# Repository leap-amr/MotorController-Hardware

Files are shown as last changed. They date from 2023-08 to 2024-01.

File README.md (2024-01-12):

# MotorController-Hardware
モータドライバのハードウェア設計のためのリポジトリ

# Image
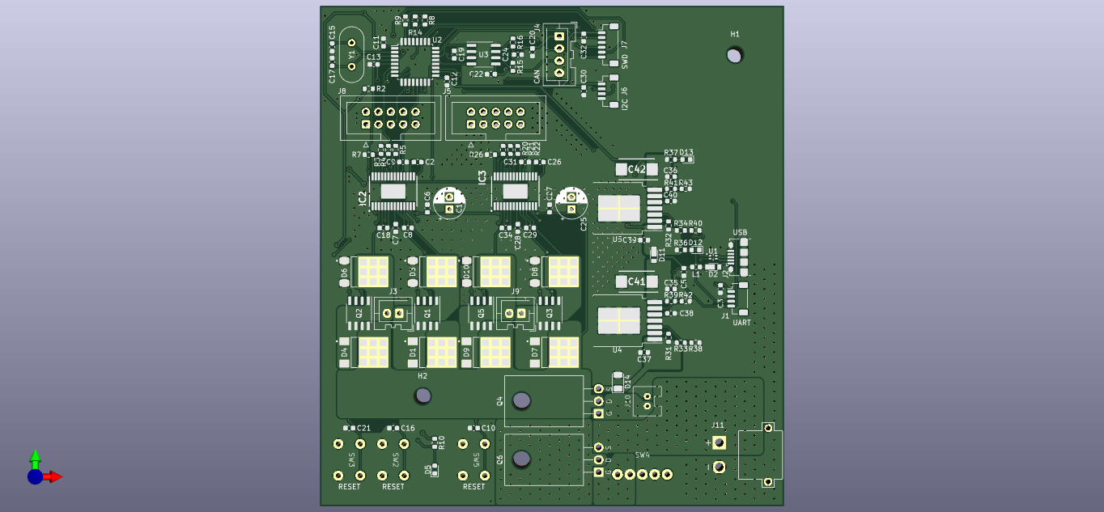
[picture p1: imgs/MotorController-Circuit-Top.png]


# Development Software Versions
Application: KiCad x64 on x64

Version: 7.0.6, release build

Libraries:
    wxWidgets 3.2.2
    FreeType 2.12.1
    HarfBuzz 6.0.0
    FontConfig 2.14.1
    libcurl/7.88.1-DEV Schannel zlib/1.2.13

Platform: Windows 10 (build 19045), 64-bit edition, 64 bit, Little endian, wxMSW

    Build Info:
    Date: Jul  6 2023 04:56:45
    wxWidgets: 3.2.2 (wchar_t,wx containers)
    Boost: 1.81.0
    OCC: 7.6.3
    Curl: 7.88.1-DEV
    ngspice: 40
    Compiler: Visual C++ 1936 without C++ ABI

Build settings:
    KICAD_SPICE=ON

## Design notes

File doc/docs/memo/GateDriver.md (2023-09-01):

# GateDriver
## A3921

### Functional Block Diagram
#### $C_{REG}$
A3921 内部にある 13 V にレギュレートされたピン $V_{REG}$ ピンと GND の間に接続する。

具体的な値の決め方は書いてない。

#### $C_p$
チャージポンプレギュレータに接続するコンデンサ。

200 nF 以上である必要があるが、通常 470 nF をつけておけば良いらしい。

#### $C_{BOOTA}, C_{BOOTB}$
ブートストラップに使用するコンデンサ。

ゲート電圧をより高くすハイサイドゲートを駆動するのに必要になる。

容量は

$$C_{BOOT} = \frac{Q_{GATE} \times 20}{V_{BOOT}}$$

で決めることができる。

|変数|説明|今回の回路の具体的な値
|:---:|:---
|$Q_{GATE}$|ゲート駆動に必要な電荷量|28 nC
|$V_{BOOT}$|ゲート駆動に必要な電圧|1.8 V

$Q_{BOOT} >> Q_{GATE}$ を満たす必要があり、ここでは $Q_{BOOT}$ を $Q_{GATE}$ の 20 倍の大きさを目安にしている。

∴311.111 nC 以上のコンデンサを選定する必要がある。

#### $R_{GHA}, R_{GHB}$
#### $R_{GLA}, R_{GLB}$
#### $R_{DEAD}$
#### V5
#### FF1, FF2
#### $V_{DSTH}$
#### SR
#### RESET

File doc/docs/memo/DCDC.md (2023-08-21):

# DC/DC Convertor
## TPSM13604HNDWR

### Typical Application
#### $R_{ENT}, R_{ENB}$
EN ピンの電圧が 1.18 V より大きいか小さいかで DC/DC コンバータの有効無効が決まる。

V_IN を分圧して、V_IN の電圧が規定値を下回った時に、EN ピンが 1.18 V を下回るように分圧抵抗を決める。

DC/DC コンバータが有効になる条件式

$$\frac{R_{ENB}}{R_{ENT} + R_{ENB}} \times V_{IN} \ge 1.18 [V]$$

#### $R_{FBT}, R_{FBB}$
FB ピンの電圧が 0.8 V より大きいか小さいかで DC/DC コンバータのパルス出力を有効にするか無効にするかが決まる。

V_OUT を分圧して、V_OUT の電圧が規定値を下回った時に、FB ピンが 0.8 V を下回るように分圧抵抗を決める。

出力電圧の式

$$\frac{R_{FBB}}{R_{FBT} + R_{FBB}} \times V_{OUT} = 0.8 [V]$$

出力電圧を 5 V にしたいときは $V_{OUT}$ を 5 V にする。

尚、これらの抵抗 $R_{FBT}, R_{FBB}$ の値は 1k ~ 50k $\Omega$ の範囲で選択する必要がある。

#### $C_{SS}$
推奨値 : 4700 pF

出力電圧が安定するまでの時間 $t_{SS}$ に関わる。

この時間は、早すぎると出力電圧がオーバーシュートし、遅すぎると目的の出力電圧を得るのに時間がかかってしまう。

$$t_{SS} = 0.8 [V] \times \frac{C_{SS}}{0.8 [\mu A]}$$

という式で求めることが可能だが、$t_{SS}= 0 .5 [ms]$ が推奨値とされているため、$C_{{SS}} = 4700 [pF]$ が推奨とされる。

#### $C_{OUT}$
推奨コンデンサ : セラミックコンデンサ or ポリマー電解コンデンサ

$$C_{OUT} \ge I_{STEP} \times V_{FB} \times L \times \frac{V_{IN}}{4 \times V_{OUT} \times (V_{IN} - V_{OUT}) \times V_{OUT-TRAN}}$$

ここで、

- $V_{FB}$ は FB ピンの閾値 0.8 V
- $L$ はインダクタのリアクタンス 10 $\mu H$
- $V_{OUT-TRAN}$ はなんだよこれ 例として $V_{OUT-TRAN} = 50 [mV]$ になってる
- $I_{STEP}$ はおそらく最大出力電流 DC/DC  の最大出力電流が 4 A であるためこれ以下にする
- $V_{IN}, V_{OUT}$ はそれぞれ入力電圧と出力電圧

これらによって $C_{OUT}$ の最小値が決定される。

この条件を満たしたうえで、低 ESR のコンデンサを設定する。

この ESR の最大値も計算式が用意されているがよくわからん。

#### $R_{ON}$
スイッチング周波数を決定する抵抗。

以下の式でスイッチング周波数 $f_{SW(CCM)}$ が決定される。

$$f_{SW(CCM)} \approxeq \frac{V_{OUT}}{(1.3\times10^{-10}\times R_{ON}}$$

#### $C_{IN}$
$$C_{IN} \geq \frac{I_{OUT} \times D \times ( 1 - D)}{f_{SW-CCM} \times \Delta{V_{IN}}}$$
$$D \approxeq \frac{V_{OUT}}{V_{IN}}$$

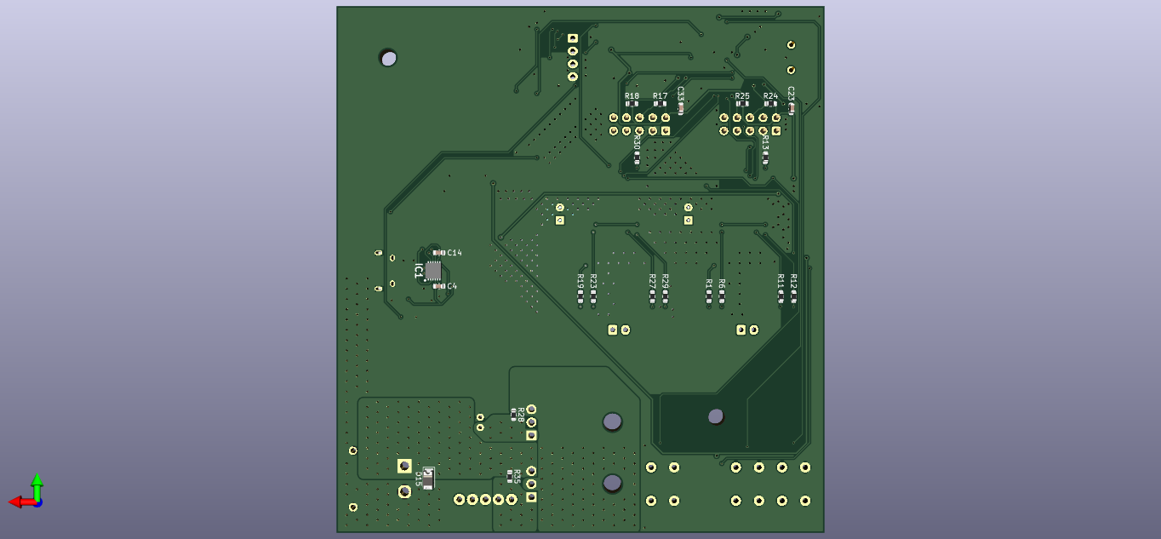
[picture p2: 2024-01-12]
imgs/MotorController-3D-Bottom.png

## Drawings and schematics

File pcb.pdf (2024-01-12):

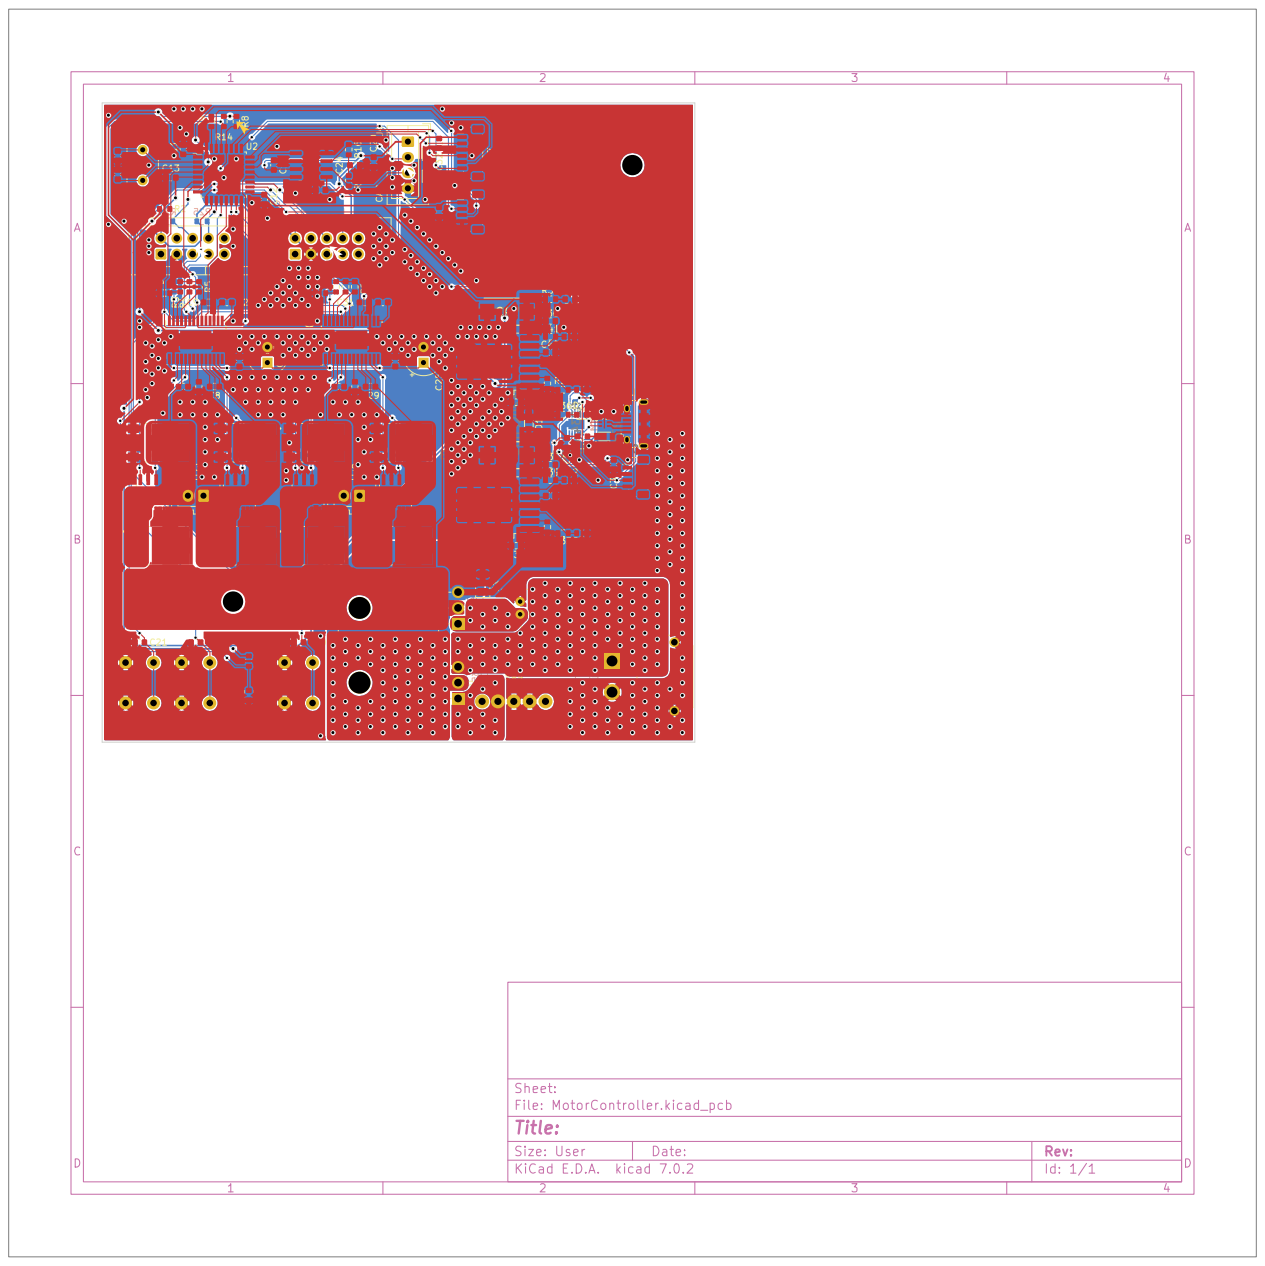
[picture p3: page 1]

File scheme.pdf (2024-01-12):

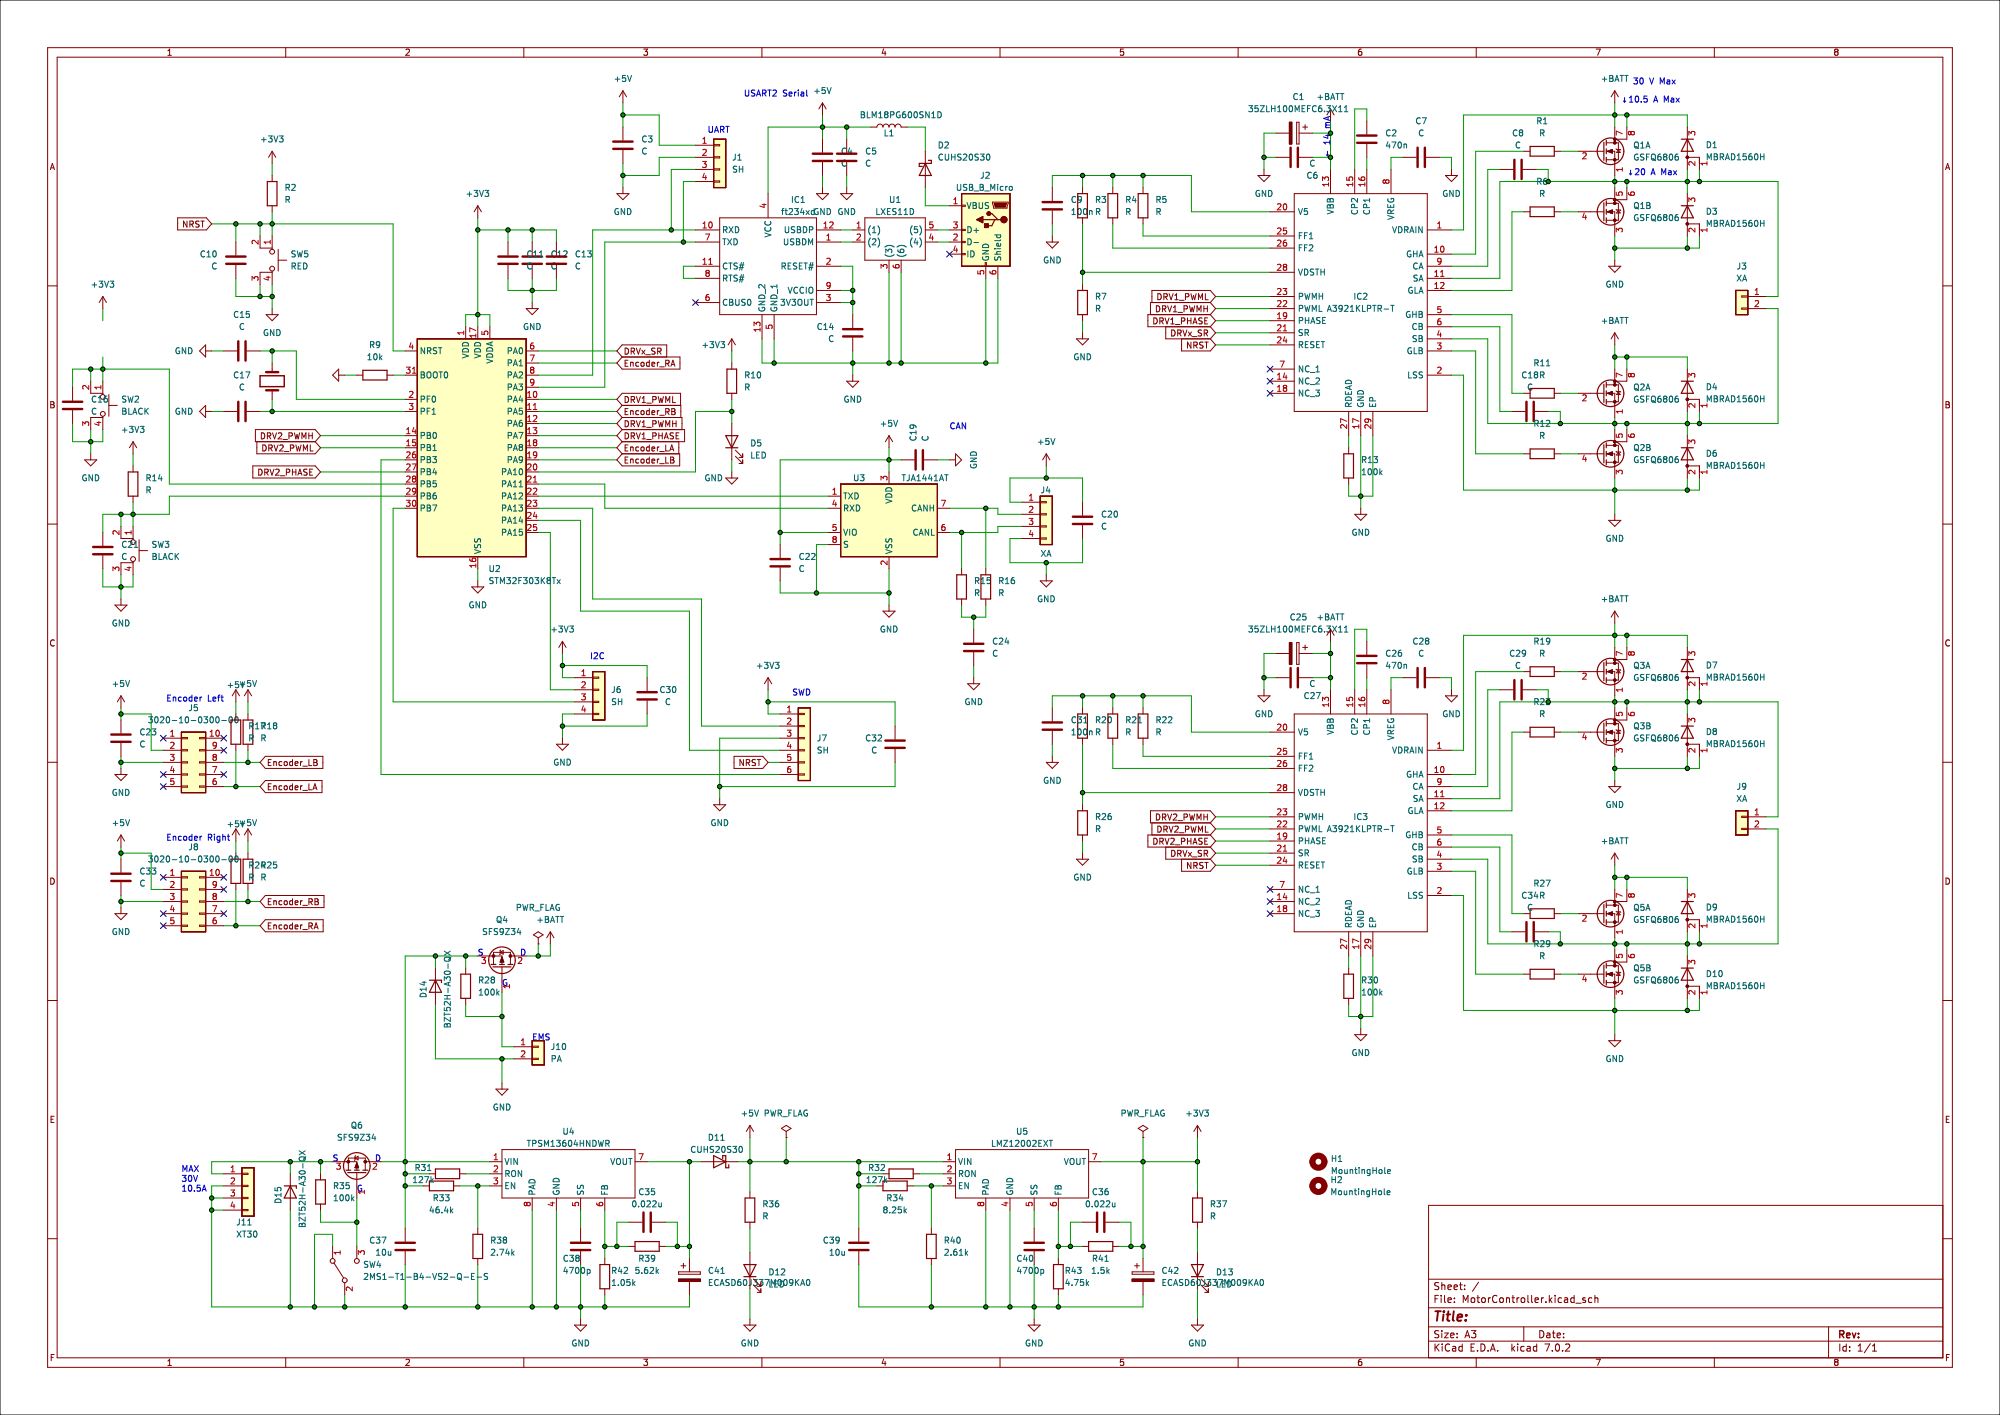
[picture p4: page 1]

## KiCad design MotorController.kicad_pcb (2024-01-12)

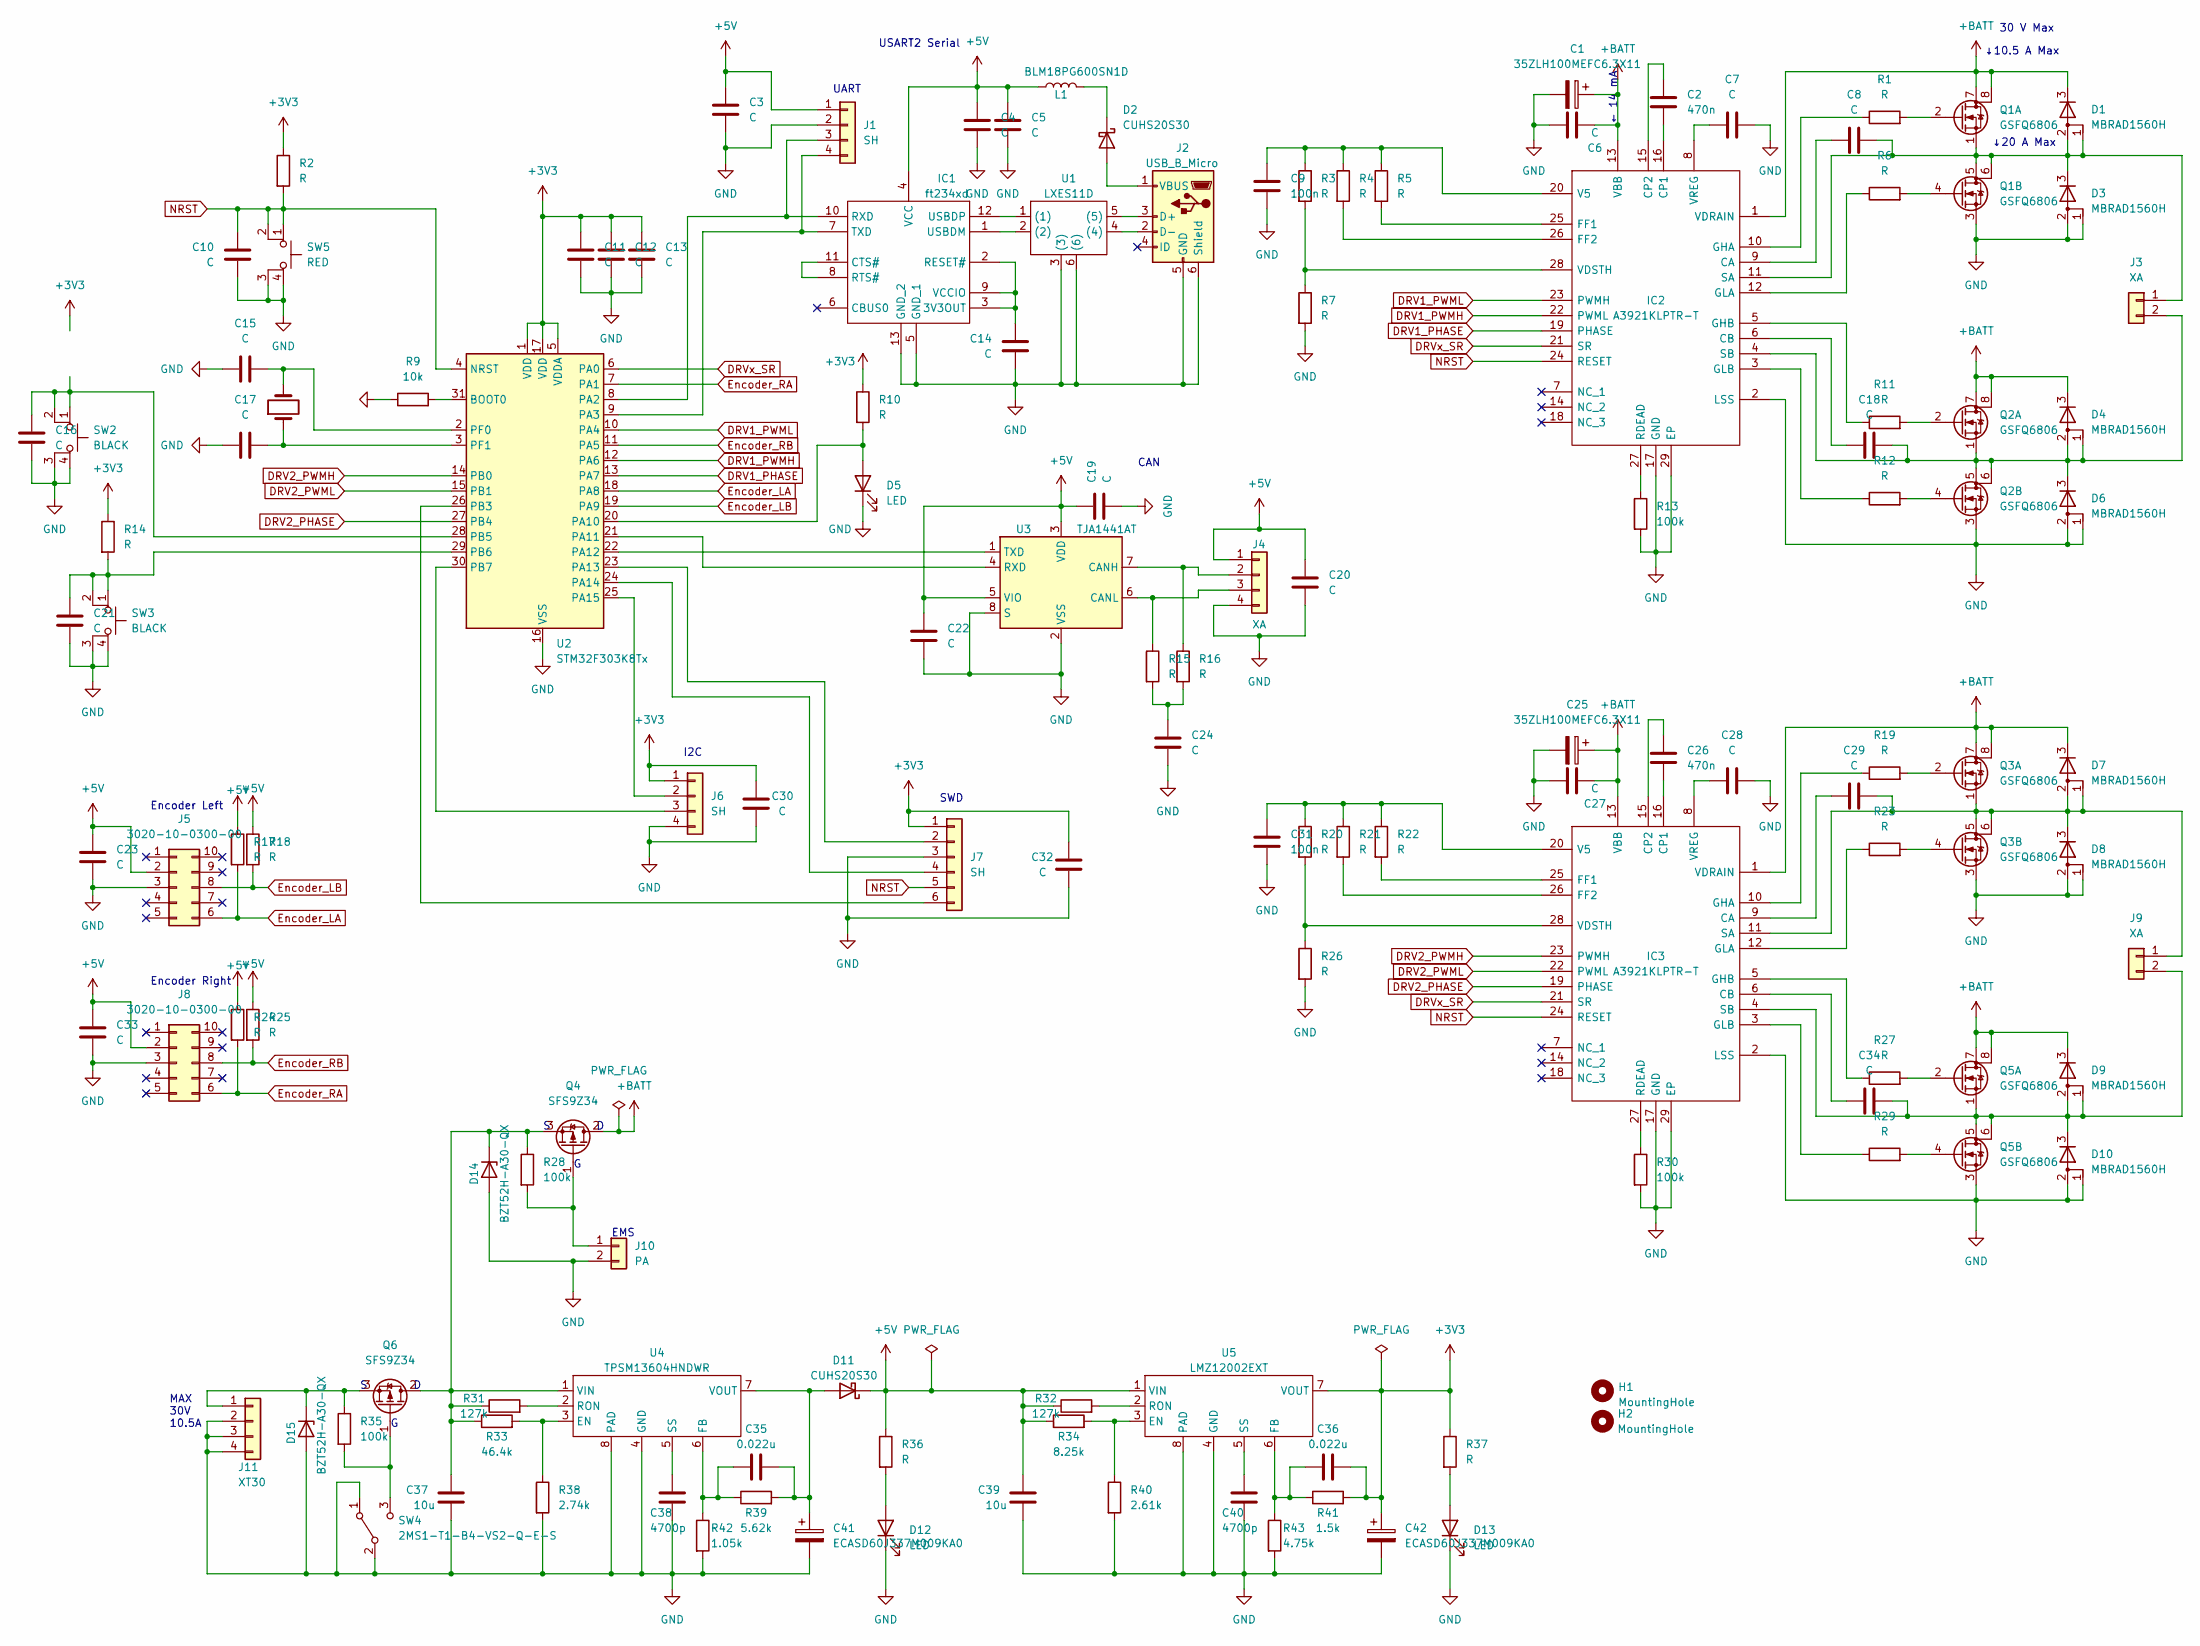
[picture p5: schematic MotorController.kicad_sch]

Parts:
C1, C25: 35ZLH100MEFC6.3X11; CP_Radial_D6.3mm_P2.50mm
C2, C26: 470n; C_0603_1608Metric
C3, C4, C5, C6, C7, C8, C10, C11, C12, C13, C14, C15, C16, C17, C18, C19, C20, C21, C22, C23, C24, C27, C28, C29, C30, C32, C33, C34: C; C_0603_1608Metric
C9, C31: 100n; C_0603_1608Metric
C35, C36: 0.022u; C_0603_1608Metric
C37, C39: 10u; C_0603_1608Metric
C38, C40: 4700p; C_0603_1608Metric
C41, C42: ECASD60J337M009KA0; CAPPM7343X310N
D1, D3, D4, D6, D7, D8, D9, D10: MBRAD1560H; DIO_MBRAD1560H
D2, D11: CUHS20S30; CUHS20S40H3F
D5, D12, D13: LED; LED_0603_1608Metric
D14, D15: BZT52H-A30-QX; D_1206_3216Metric
H1, H2: MountingHole; MountingHole_3.2mm_M3
IC1: ft234xd; SON45P300X300X80-13N-D; Manufacturer_Part_Number ft234xd
IC2, IC3: A3921KLPTR-T; A3944KLPTRT; Manufacturer_Part_Number A3921KLPTR-T; Mouser Part Number 250-A3921KLPTR-T
J1, J6: SH; JST_SH_BM04B-SRSS-TB_1x04-1MP_P1.00mm_Vertical
J2: USB_B_Micro; USB_Micro-B_Amphenol_10118194_Horizontal
J3, J9: XA; JST_XA_B02B-XASK-1-A_1x02_P2.50mm_Vertical
J4: XA; JST_XA_B04B-XASK-1-A_1x04_P2.50mm_Vertical
J5, J8: 3020-10-0300-00; IDC-Header_2x05_P2.54mm_Vertical
J7: SH; JST_SH_BM06B-SRSS-TB_1x06-1MP_P1.00mm_Vertical
J10: PA; PA_01x02
J11: XT30; XT30PWM
L1: BLM18PG600SN1D; L_0603_1608Metric
Q1, Q2, Q3, Q5: GSFQ6806; SO-8_3.9x4.9mm_P1.27mm
Q4, Q6: SFS9Z34; TO-220F-3_Horizontal_TabDown
R1, R2, R3, R4, R5, R6, R7, R10, R11, R12, R14, R15, R16, R17, R18, R19, R20, R21, R22, R23, R24, R25, R26, R27, R29, R36, R37: R; R_0603_1608Metric
R9: 10k; R_0603_1608Metric
R13, R28, R30, R35: 100k; R_0603_1608Metric
R31, R32: 127k; R_0603_1608Metric
R33: 46.4k; R_0603_1608Metric
R34: 8.25k; R_0603_1608Metric
R38: 2.74k; R_0603_1608Metric
R39: 5.62k; R_0603_1608Metric
R40: 2.61k; R_0603_1608Metric
R41: 1.5k; R_0603_1608Metric
R42: 1.05k; R_0603_1608Metric
R43: 4.75k; R_0603_1608Metric
SW2, SW3: BLACK; DTS-63-N-V-BLK(TS-0606-F-N
SW4: 2MS1-T1-B4-VS2-Q-E-S
SW5: RED; DTS-63-N-V-BLK(TS-0606-F-N
U1: LXES11D; LXES11DAA2135
U2: STM32F303K8Tx; LQFP-32_7x7mm_P0.8mm
U3: TJA1441AT; SOIC-8_3.9x4.9mm_P1.27mm
U4: TPSM13604HNDWR; Texas_NDW-7_TabPin8
U5: LMZ12002EXT; Texas_NDW-7_TabPin8
Y1: 32M; Crystal_HC49-4H_Vertical

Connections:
+3V3: C11.1, C12.1, C13.1, C30.1, C32.1, C36.2, C42.1, J6.1, J7.1, R2.1, R10.1, R14.1, R37.1, R41.2, U2.1 (VDD), U2.5 (VDDA), U2.17 (VDD), U5.7 (VOUT); also elsewhere on the board
+5V: C3.1, C4.1, C5.1, C19.1, C20.1, C22.1, C23.1, C33.1, C39.1, D11.1 (K), IC1.4 (VCC), J1.1, J4.1, J5.2, J8.2, L1.1, R17.1, R18.1, R24.1, R25.1, R32.1, R34.1, R36.1, U3.3 (VDD), U3.5 (VIO), U5.1 (VIN)
+BATT: C1.1, C6.2, C25.1, C27.2, D1.3 (K), D4.3 (K), D7.3 (K), D9.3 (K), IC2.1 (VDRAIN), IC2.13 (VBB), IC3.1 (VDRAIN), IC3.13 (VBB), Q1.7 (D), Q1.8 (D), Q2.7 (D), Q2.8 (D), Q3.7 (D), Q3.8 (D), Q4.2 (D), Q5.7 (D), Q5.8 (D)
DRV1_PHASE: IC2.19 (PHASE), U2.13 (PA7)
DRV1_PWMH: IC2.22 (PWML), U2.12 (PA6)
DRV1_PWML: IC2.23 (PWMH), U2.10 (PA4)
DRV2_PHASE: IC3.19 (PHASE), U2.27 (PB4)
DRV2_PWMH: IC3.23 (PWMH), U2.14 (PB0)
DRV2_PWML: IC3.22 (PWML), U2.15 (PB1)
DRVx_SR: IC2.21 (SR), IC3.21 (SR), U2.6 (PA0)
Encoder_LA: J5.6, R17.2, U2.18 (PA8)
Encoder_LB: J5.8, R18.2, U2.19 (PA9)
Encoder_RA: J8.6, R24.2, U2.7 (PA1)
Encoder_RB: J8.8, R25.2, U2.11 (PA5)
GND: C1.2, C3.2, C4.2, C5.2, C6.1, C7.2, C9.2, C10.2, C11.2, C12.2, C13.2, C14.2, C15.1, C16.2, C17.1, C19.2, C20.2, C21.2, C22.2, C23.2, C24.2, C25.2, C27.1, C28.2, C30.2, C31.2, C32.2, C33.2, C37.2, C38.2, C39.2, C40.2, C41.2, C42.2, D3.1 (A), D3.2 (A), D5.1 (K), D6.1 (A), D6.2 (A), D8.1 (A), D8.2 (A), D10.1 (A), D10.2 (A), D12.1 (K), D13.1 (K), D14.2 (A), D15.2 (A), IC1.5 (GND_1), IC1.13 (GND_2), IC2.2 (LSS), IC2.17 (GND), IC2.29 (EP), IC3.2 (LSS), IC3.17 (GND), IC3.29 (EP), J1.2, J2.5 (GND), J2.6 (Shield), J4.4, J5.3, J6.4, J7.3, J8.3, J10.2, J11.2, J11.3, J11.4, Q1.3 (S), Q2.3 (S), Q3.3 (S), Q5.3 (S), R7.2, R9.1, R13.2, R26.2, R30.2, R38.2, R40.2, R42.2, R43.2, SW2.3 (K), SW2.4 (A), SW3.3 (K), SW3.4 (A), SW4.1 (A), SW4.2 (B), SW5.3 (K), SW5.4 (A), U1.3 ((3)), U1.6 ((6)), U2.16 (VSS), U2.32 (VSS), U3.2 (VSS), U3.8 (S), U4.4 (GND), U4.8 (PAD), U5.4 (GND), U5.8 (PAD)
NRST: C10.1, IC2.24 (RESET), IC3.24 (RESET), J7.5, R2.2, SW5.1, SW5.2, U2.4 (NRST)
unnamed: C24.1, R15.2, R16.2
unnamed: D2.2 (A), J2.1 (VBUS)
unnamed: D2.1 (K), L1.2
unnamed: C8.1, D1.1 (A), D1.2 (A), D3.3 (K), IC2.11 (SA), J3.1, Q1.1 (S), Q1.5 (D), Q1.6 (D)
unnamed: D5.2 (A), R10.2, U2.20 (PA10)
unnamed: C18.1, D4.1 (A), D4.2 (A), D6.3 (K), IC2.4 (SB), J3.2, Q2.1 (S), Q2.5 (D), Q2.6 (D)
unnamed: C29.1, D7.1 (A), D7.2 (A), D8.3 (K), IC3.11 (SA), J9.1, Q3.1 (S), Q3.5 (D), Q3.6 (D)
unnamed: C34.1, D9.1 (A), D9.2 (A), D10.3 (K), IC3.4 (SB), J9.2, Q5.1 (S), Q5.5 (D), Q5.6 (D)
unnamed: C35.2, C41.1, D11.2 (A), R39.2, U4.7 (VOUT)
unnamed: D12.2 (A), R36.2
unnamed: D13.2 (A), R37.2
unnamed: C37.1, D14.1 (K), Q4.3 (S), Q6.2 (D), R28.1, R31.1, R33.1, U4.1 (VIN)
unnamed: D15.1 (K), J11.1, Q6.3 (S), R35.1
unnamed: C14.1, IC1.2 (RESET#), IC1.3 (3V3OUT), IC1.9 (VCCIO)
unnamed: IC1.8 (RTS#), IC1.11 (CTS#)
unnamed: IC1.10 (RXD), J1.3, U2.8 (PA2)
unnamed: IC1.7 (TXD), J1.4, U2.9 (PA3)
unnamed: IC1.1 (USBDM), U1.2 ((2))
unnamed: IC1.12 (USBDP), U1.1 ((1))
unnamed: C8.2, IC2.9 (CA)
unnamed: C18.2, IC2.6 (CB)
unnamed: C2.1, IC2.16 (CP1)
unnamed: C2.2, IC2.15 (CP2)
unnamed: IC2.25 (FF1), R5.2
unnamed: IC2.26 (FF2), R4.2
unnamed: IC2.10 (GHA), R1.1
unnamed: IC2.5 (GHB), R11.1
unnamed: IC2.12 (GLA), R6.1
unnamed: IC2.3 (GLB), R12.1
unnamed: IC2.27 (RDEAD), R13.1
unnamed: C9.1, IC2.20 (V5), R3.1, R4.1, R5.1
unnamed: IC2.28 (VDSTH), R3.2, R7.1
unnamed: C7.1, IC2.8 (VREG)
unnamed: C29.2, IC3.9 (CA)
unnamed: C34.2, IC3.6 (CB)
unnamed: C26.1, IC3.16 (CP1)
unnamed: C26.2, IC3.15 (CP2)
unnamed: IC3.25 (FF1), R22.2
unnamed: IC3.26 (FF2), R21.2
unnamed: IC3.10 (GHA), R19.1
unnamed: IC3.5 (GHB), R27.1
unnamed: IC3.12 (GLA), R23.1
unnamed: IC3.3 (GLB), R29.1
unnamed: IC3.27 (RDEAD), R30.1
unnamed: C31.1, IC3.20 (V5), R20.1, R21.1, R22.1
unnamed: IC3.28 (VDSTH), R20.2, R26.1
unnamed: C28.1, IC3.8 (VREG)
unnamed: J2.3 (D+), U1.5 ((5))
unnamed: J2.2 (D-), U1.4 ((4))
unnamed: J4.2, R16.1, U3.7 (CANH)
unnamed: J4.3, R15.1, U3.6 (CANL)
unnamed: J6.2, U2.25 (PA15)
unnamed: J6.3, U2.30 (PB7)
unnamed: J7.2, U2.23 (PA13)
unnamed: J7.4, U2.24 (PA14)
unnamed: J7.6, U2.26 (PB3)
unnamed: J10.1, Q4.1 (G), R28.2
unnamed: Q1.2 (G), R1.2
unnamed: Q1.4 (G), R6.2
unnamed: Q2.2 (G), R11.2
unnamed: Q2.4 (G), R12.2
unnamed: Q3.2 (G), R19.2
unnamed: Q3.4 (G), R23.2
unnamed: Q5.2 (G), R27.2
unnamed: Q5.4 (G), R29.2
unnamed: Q6.1 (G), R35.2, SW4.3 (C)
unnamed: R9.2, U2.31 (BOOT0)
unnamed: U2.21 (PA11), U3.4 (RXD)
unnamed: U2.22 (PA12), U3.1 (TXD)
unnamed 85: C16.1, SW2.1, SW2.2, U2.28 (PB5); also elsewhere on the board
unnamed: C21.1, R14.2, SW3.1, SW3.2, U2.29 (PB6)
unnamed: C15.2, U2.2 (PF0), Y1.2
unnamed: C17.2, U2.3 (PF1), Y1.1
unnamed: R33.2, R38.1, U4.3 (EN)
unnamed: C35.1, R39.1, R42.1, U4.6 (FB)
unnamed: R31.2, U4.2 (RON)
unnamed: C38.1, U4.5 (SS)
unnamed: R34.2, R40.1, U5.3 (EN)
unnamed: C36.1, R41.1, R43.1, U5.6 (FB)
unnamed: R32.2, U5.2 (RON)
unnamed: C40.1, U5.5 (SS)

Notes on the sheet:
Encoder Right
USART2 Serial
↓20 A Max
UART
MAX 30V 10.5A
CAN
↓10.5 A Max
I2C
← 14 mA
SWD
Encoder Left
EMS
30 V Max

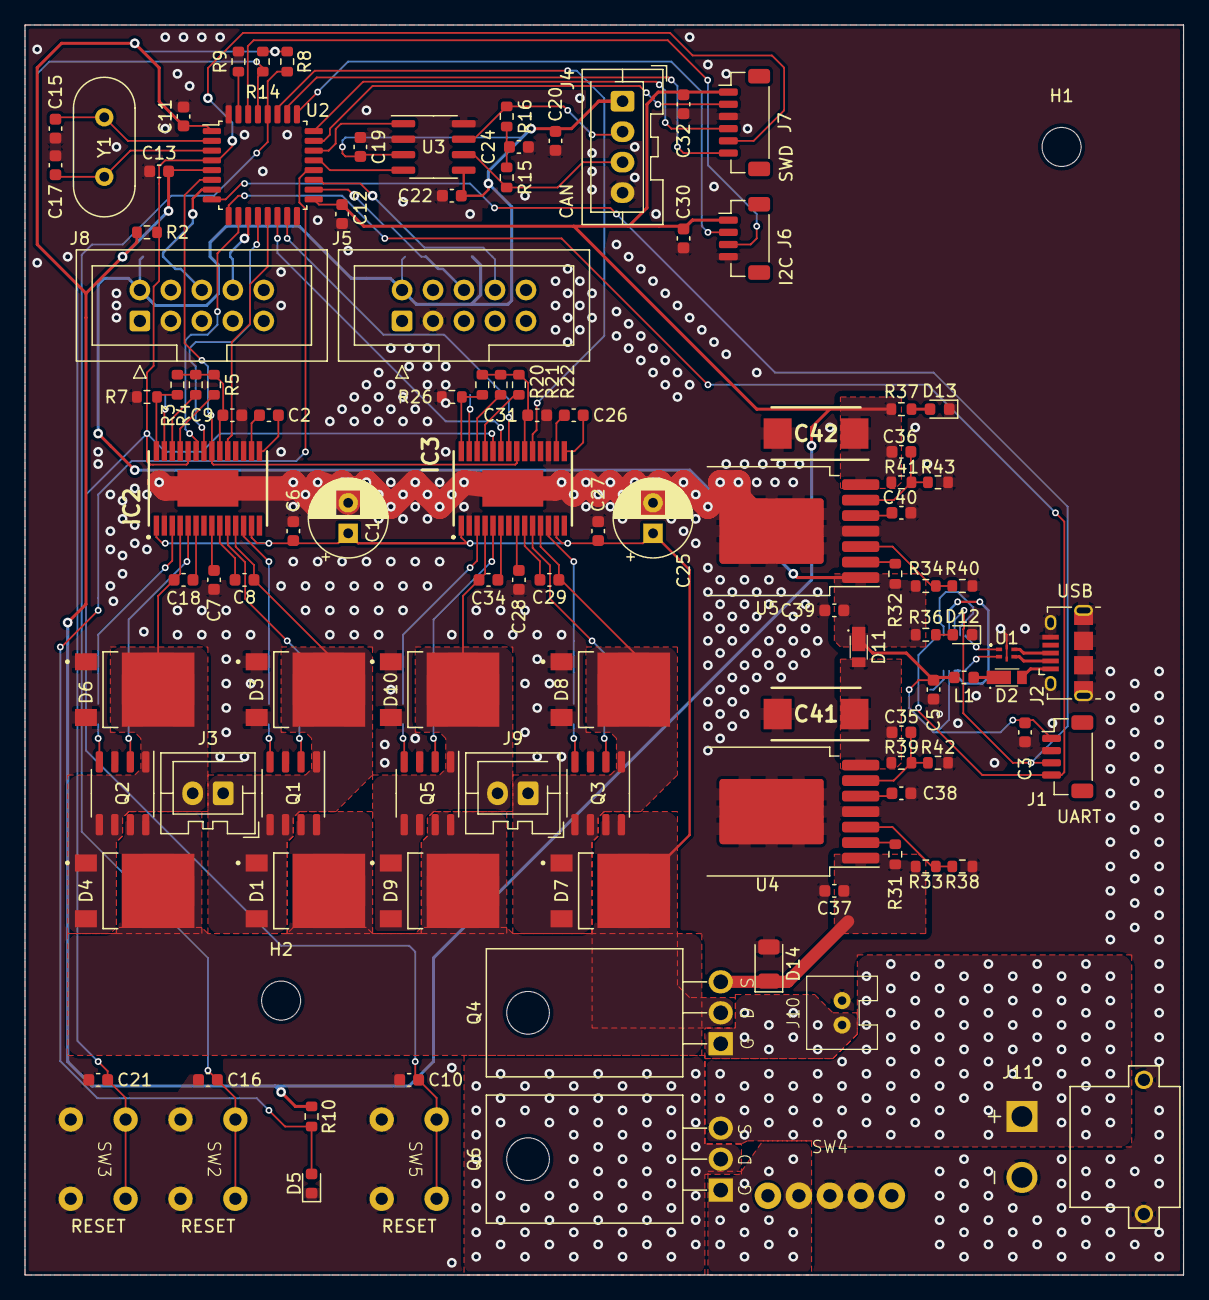
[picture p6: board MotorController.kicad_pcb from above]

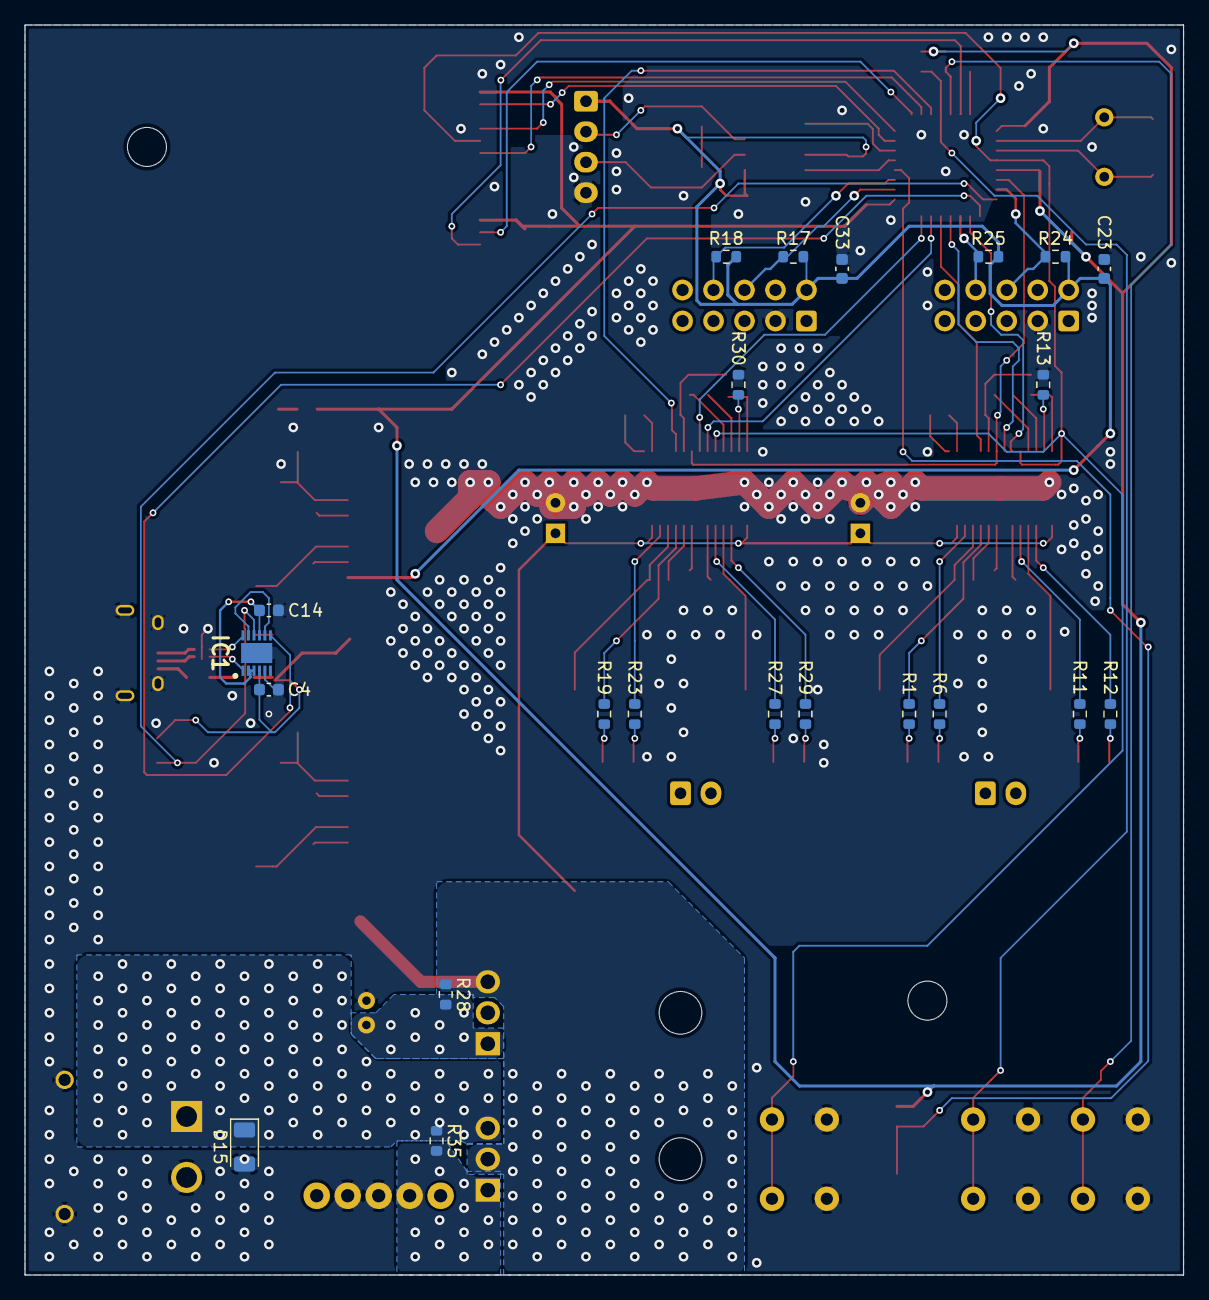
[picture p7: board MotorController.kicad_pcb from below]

Board: 2 copper layers, 95.0 x 102.5 mm, 133 parts (22 on the bottom side), 97 nets.

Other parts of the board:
R8: R; R_0603_1608Metric

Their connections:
+3V3: R8.1; also elsewhere on the board
unnamed 85: R8.2; also elsewhere on the board

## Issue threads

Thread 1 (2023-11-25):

[ Discussion ] ビアを通したリターンパス

YazawaKenichi, 2023-11-25:
# 不安な内容
こういう配線。。。大丈夫？
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

`Net-(IC1-RXD)` は UART の RX ( TX ) が通る。

YazawaKenichi, 2023-11-25:
不安なのは、右から左に流れる信号が、ビアをとおして突然右から左に流れてしまうということ。

YazawaKenichi, 2023-11-25:
直角配線がダメな理由は、PCB を印刷した時に鋭角部分によくわからんゴミ（ノイズの元凶）が残ってしまうから。

そう考えると、このビア配線はゴミを残さないので問題ない気がする。

右から左に信号を通して、ビアを通して、また左に流しても、電流から見れば大して大きな違いは無いような気がする。

ただただ不安。

YazawaKenichi, 2023-11-30:
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

これに更新された。

今度はビアを通した直角配線。

Closed 2023-11-30.

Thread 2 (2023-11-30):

[ Discussion ] LC 回路のパターン

YazawaKenichi, 2023-11-30:
# 不安な内容
LC 回路はどんな感じで L と C を設置すればいいんだろう

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

YazawaKenichi, 2023-12-16:
極端に L と C を離さなければだいたいどんな配置でも大丈夫。

極端に話したら平滑化している意味がなくなります。

YazawaKenichi, 2023-12-16:
この写真の場合、気にするべきは L1 と D2 が接近しすぎていることです。

YazawaKenichi, 2023-12-16:
しかし最新のコミットでは距離が適切に離されているため、すでに問題は解決されています。

Closed 2023-12-16.

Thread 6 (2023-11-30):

[ Discussion ] ここにツェナーはいるかいらないか

YazawaKenichi, 2023-11-30:
# 不安な内容
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

モータの逆起電力が原因で FET Vgs に 30 V 以上の電圧がかかる可能性がある。

それなのに対して FET の耐圧は 30 V ギリギリであることが問題。

対策として Vgs 間に 30 V ツェナーダイオードを挟むことで 30 V を保障する。

そう考えると EMS の方に一つツェナーが入っていれば電源側には要らない気がする。（あってもいいけど）

先輩は「電源スイッチの G-S 間にツェナーを入れて保護」と言っていたが、EMS 側ではなく電源側なのはなぜか。

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

YazawaKenichi, 2024-01-11:
自分の中でこの形が一番よさそうな気がしてきた

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

Closed 2024-01-11.

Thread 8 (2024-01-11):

[ Task ] 水晶の下に配線すんな

YazawaKenichi, 2024-01-11:
# 実装する内容

# 実装するまでのステップ
1.

# 実装する場所
-

# 具体的な実装コード
``
```
```

# 実装する際の注意点
-

# 参考になりそうなサイト
-

YazawaKenichi, 2024-01-11:
調べれば「こう配線しろ」ってのが出るはず

YazawaKenichi, 2024-01-11:
完全にこれで草
https://www.noise-counterplan.com/point/421/

YazawaKenichi, 2024-01-11:
避けた！

Closed 2024-01-11.

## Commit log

2023-08-21 でーきたー！30% の完成度の回路図！CAN 通信用の回路は置きっぱなし
    [MotorController.kicad_pcb, MotorController.kicad_sch]
2023-08-21 CAN 通信周りの端子の変更と電源スイッチの回路図を変更
    [MotorController.kicad_sch]
2023-08-21 PDF を追加
2023-08-21 れどめに KiCAD の情報干せた
2023-08-22 とりあえずコミット
2023-09-01 先輩に見せるためにいったんコミット。コネクタの回路図とか変えた
    [MotorController.kicad_sch]
2023-09-01 PDF を更新
2023-09-08 A3921 の回路を訂正・USB 5V から DCDC 5V に入り込まないようにした・IC1 にパスコン追加
    [MotorController.kicad_sch]
2023-09-08 緊急停止スイッチをマイコンではなくゲートドライバにつなげた
    [MotorController.kicad_sch]
2023-09-08 PDF の更新
2023-09-09 緊急停止スイッチがプッシュオフであることに気が付いてそれを修正
    [MotorController.kicad_sch]
2023-09-09 bak ディレクトリを削除
2023-09-09 コネクタの形状を記しておいた。余ったピンで CAN トランシーバ使えるようにした。ERC 通した。PDF も更新した
    [MotorController.kicad_sch]
2023-09-15 power flag の指定方法を変えた。+BATT の位置を Pch FET の前に置いた
    [MotorController.kicad_sch]
2023-10-09 DCDC の出力コンデンサの記号を有極性にした。H ブリッジ FET にダイオード外付けした。A3921 のリセットピンと CPU のリセットピンを共有した。安全停止をモータの電力供給の手前に追加した。安全停止を Pch FET で実現しようとした。Pch FET の型番決めた
    [MotorController.kicad_sch]
2023-10-09 フットプリントの更新
    [MotorController.kicad_sch]
2023-10-09 フットプリント再更新
    [MotorController.kicad_sch]
2023-10-09 pdf 更新
2023-10-14 追加パーツ含めてアノテーション全部終わらせた。フットプリントをグループごとに分類して分けて設置した
    [MotorController.kicad_pcb, MotorController.kicad_sch]
2023-10-27 電源回路設置完了！USB の回路設置中
    [MotorController.kicad_pcb, MotorController.kicad_sch]
2023-11-25 USB 周りの配線を少し進めた
    [MotorController.kicad_pcb]
2023-11-30 Z 実装
    [MotorController.kicad_pcb, MotorController.kicad_sch]
2023-12-04 CPU CAN MD DCDC の位置感決めた あとは UI
    [MotorController.kicad_pcb, MotorController.kicad_sch]
2023-12-13 一旦 push
2023-12-16 GND ベタを塗る直前までやった
    [MotorController.kicad_pcb, MotorController.kicad_sch]
2024-01-11 GND 以外の配線をとりあえずやった。水晶の下の配線をなくした。パーツ同士の干渉をなくした。
    [MotorController.kicad_pcb, MotorController.kicad_sch]
2024-01-12 GND アンテナ配線除去中（ビア最大サイズ 0.5 で穴だらけ
    [MotorController.kicad_pcb]
2024-01-12 size 1 drill 0.5 to size 0.8 drill 0.4
    [MotorController.kicad_pcb]
2024-01-12 DRC 通してシルク以外のエラーを修正
    [MotorController.kicad_pcb]
2024-01-12 画像と PDF の更新
    [MotorController.kicad_pcb]
